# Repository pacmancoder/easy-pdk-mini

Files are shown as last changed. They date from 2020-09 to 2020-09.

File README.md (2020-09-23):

# easy-pdk-mini

Easy PDK mini is the programmer hardware variant originated from
[easy-pdk-programmer-hardware](https://github.com/free-pdk/easy-pdk-programmer-hardware) project.

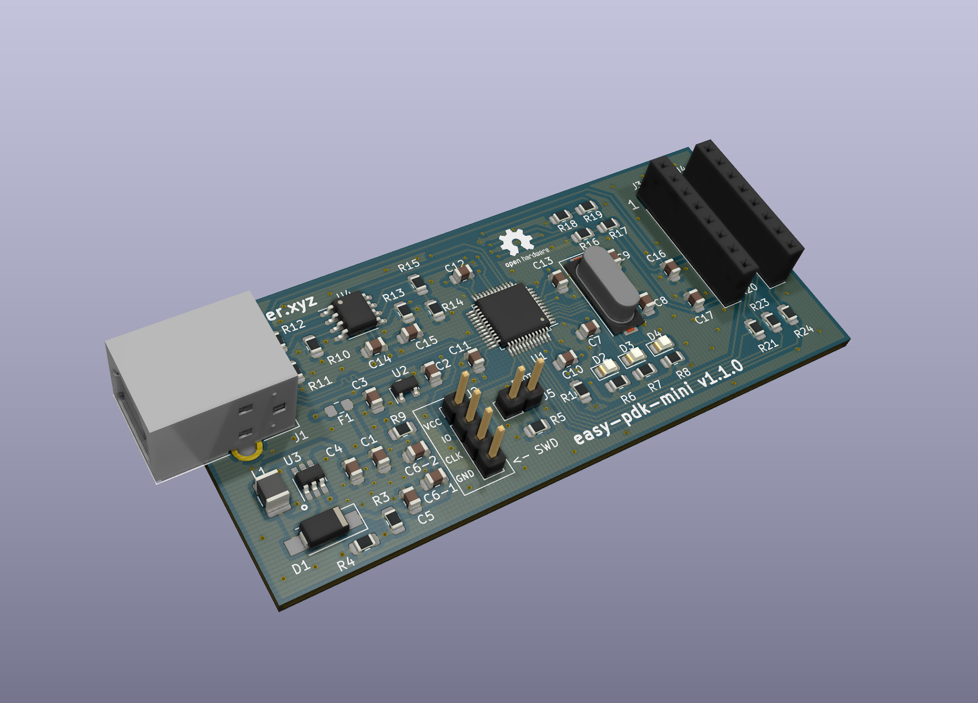
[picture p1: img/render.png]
render


Schematics was simplified and the "lite" version of the programmer by *tim_* was used as a base for
this project, so in difference with the original hardware, this version works without MOSFET boost
converter enable switch and negative voltage charge pump for the opamp.

*Interactive BOM:* [link](http://pacmancoder.xyz/easy-pdk-mini/)

### Hand soldering
All passives have at least 0805 size, and the USB-B port was used instead of micro-USB, so it
should be easy to solder this programmer by the hand. The only quirky parts which may be
hard to solder is STM32 MCU and MT3608 boost converter. 

### Changes
Although existing "lite" version of easy-pdk-programmer (which was used as a reference for this
project) is relatively simple by itself, some additional simplifications was made:
- Removed 20Ohm USB series resistors. According to STM32F072 datasheet: *"No external termination
series resistors are required on USB_DP (D+) and USB_DM (D-); the matching impedance is already
included in the embedded driver"*
- Replaced boot button with simple jumper
- Replaced 47uF boost converter output capacitor with two 22uF caps to simplify process of finding
components (In my city I was not able to find 47uF 16v, while it was easy to find 22uF 25V)
- Added pull-down resistor for PB8 to make programmer detect as "lite" hardware
- Added 500mA 6v PTC fuse

### Schematics
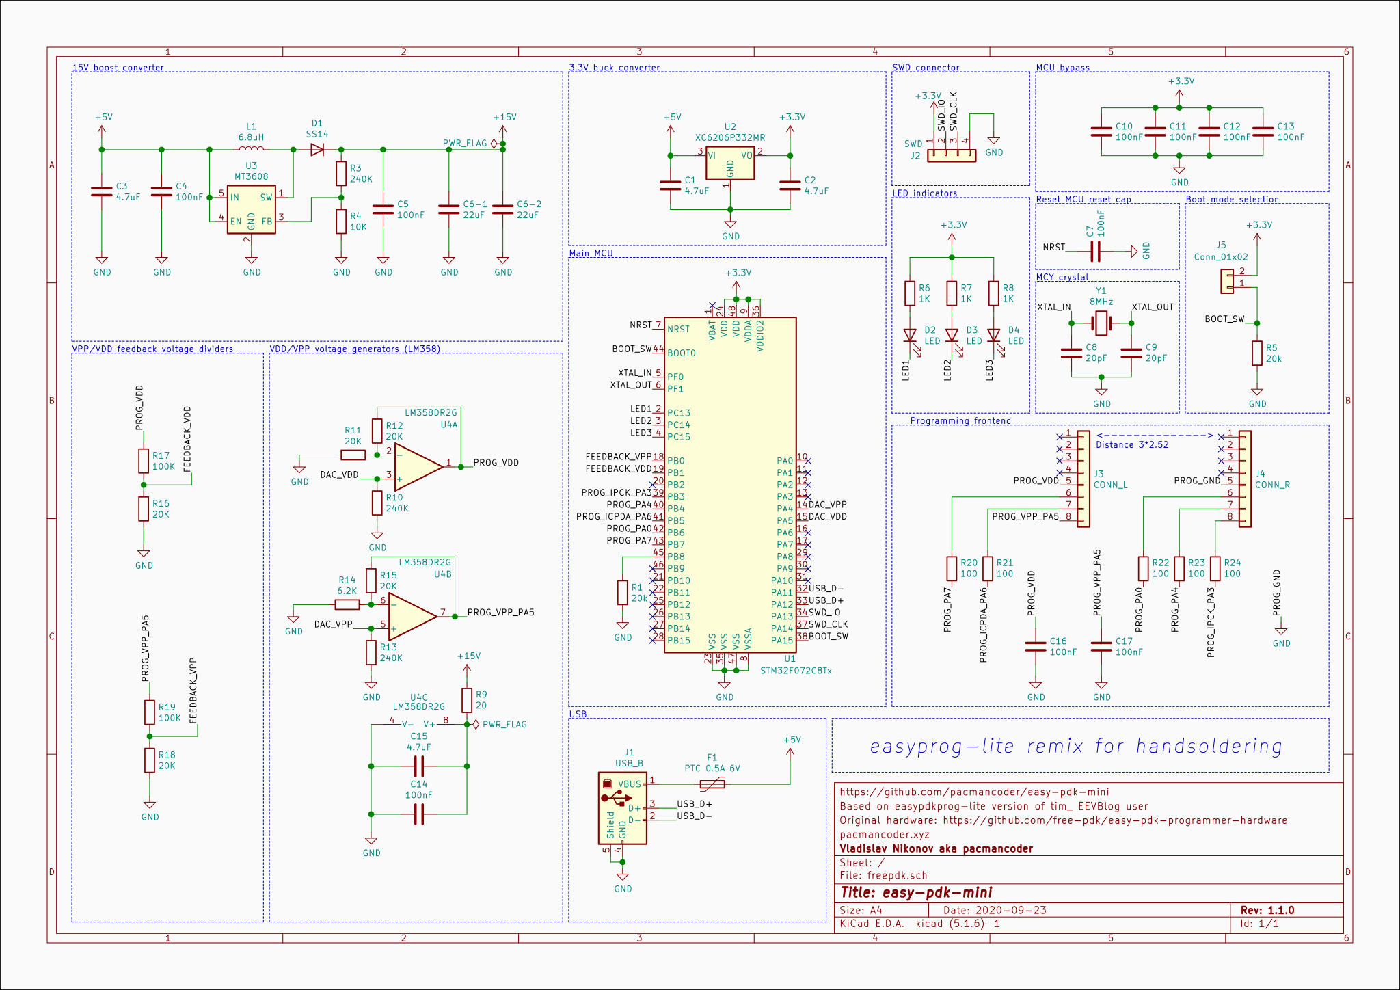
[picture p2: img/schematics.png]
schematics


### PCB
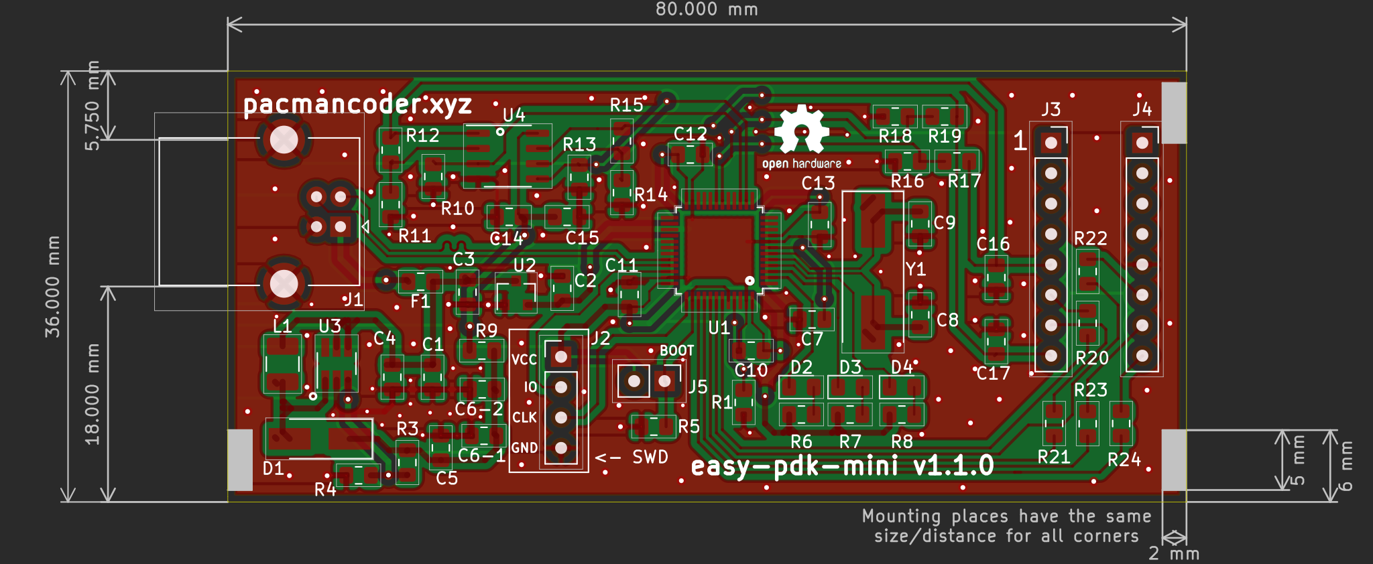
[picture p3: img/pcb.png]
pcb


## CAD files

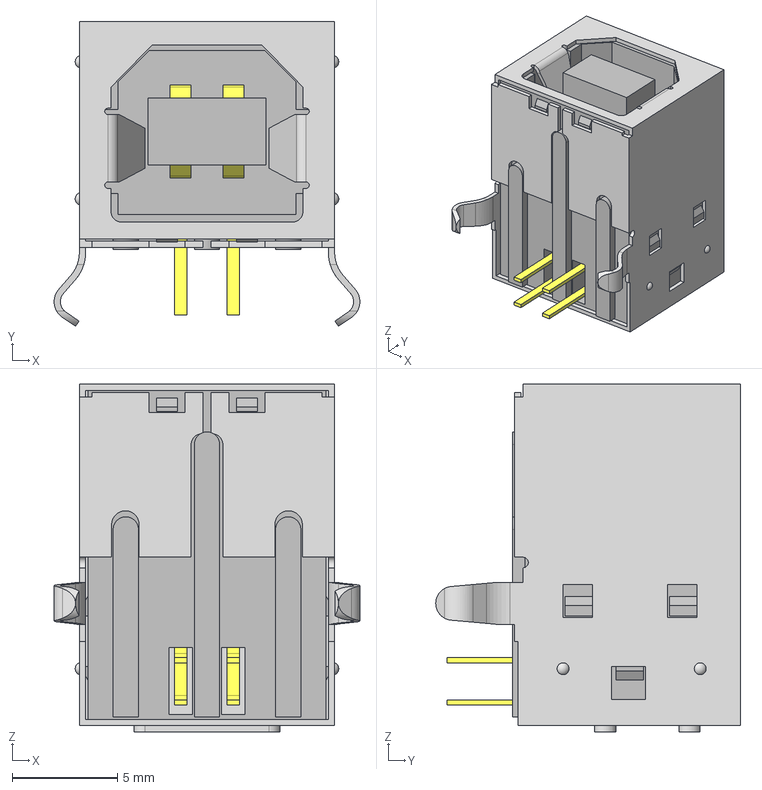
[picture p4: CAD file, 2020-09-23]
kicad/components/USB-B-S-S-B-TH-TR.stp
14.5 x 14.4 x 16.5 mm
_USB-B-S-TH_S
_USB-B-S-B-TH_B
_USB-B-S-TH_P

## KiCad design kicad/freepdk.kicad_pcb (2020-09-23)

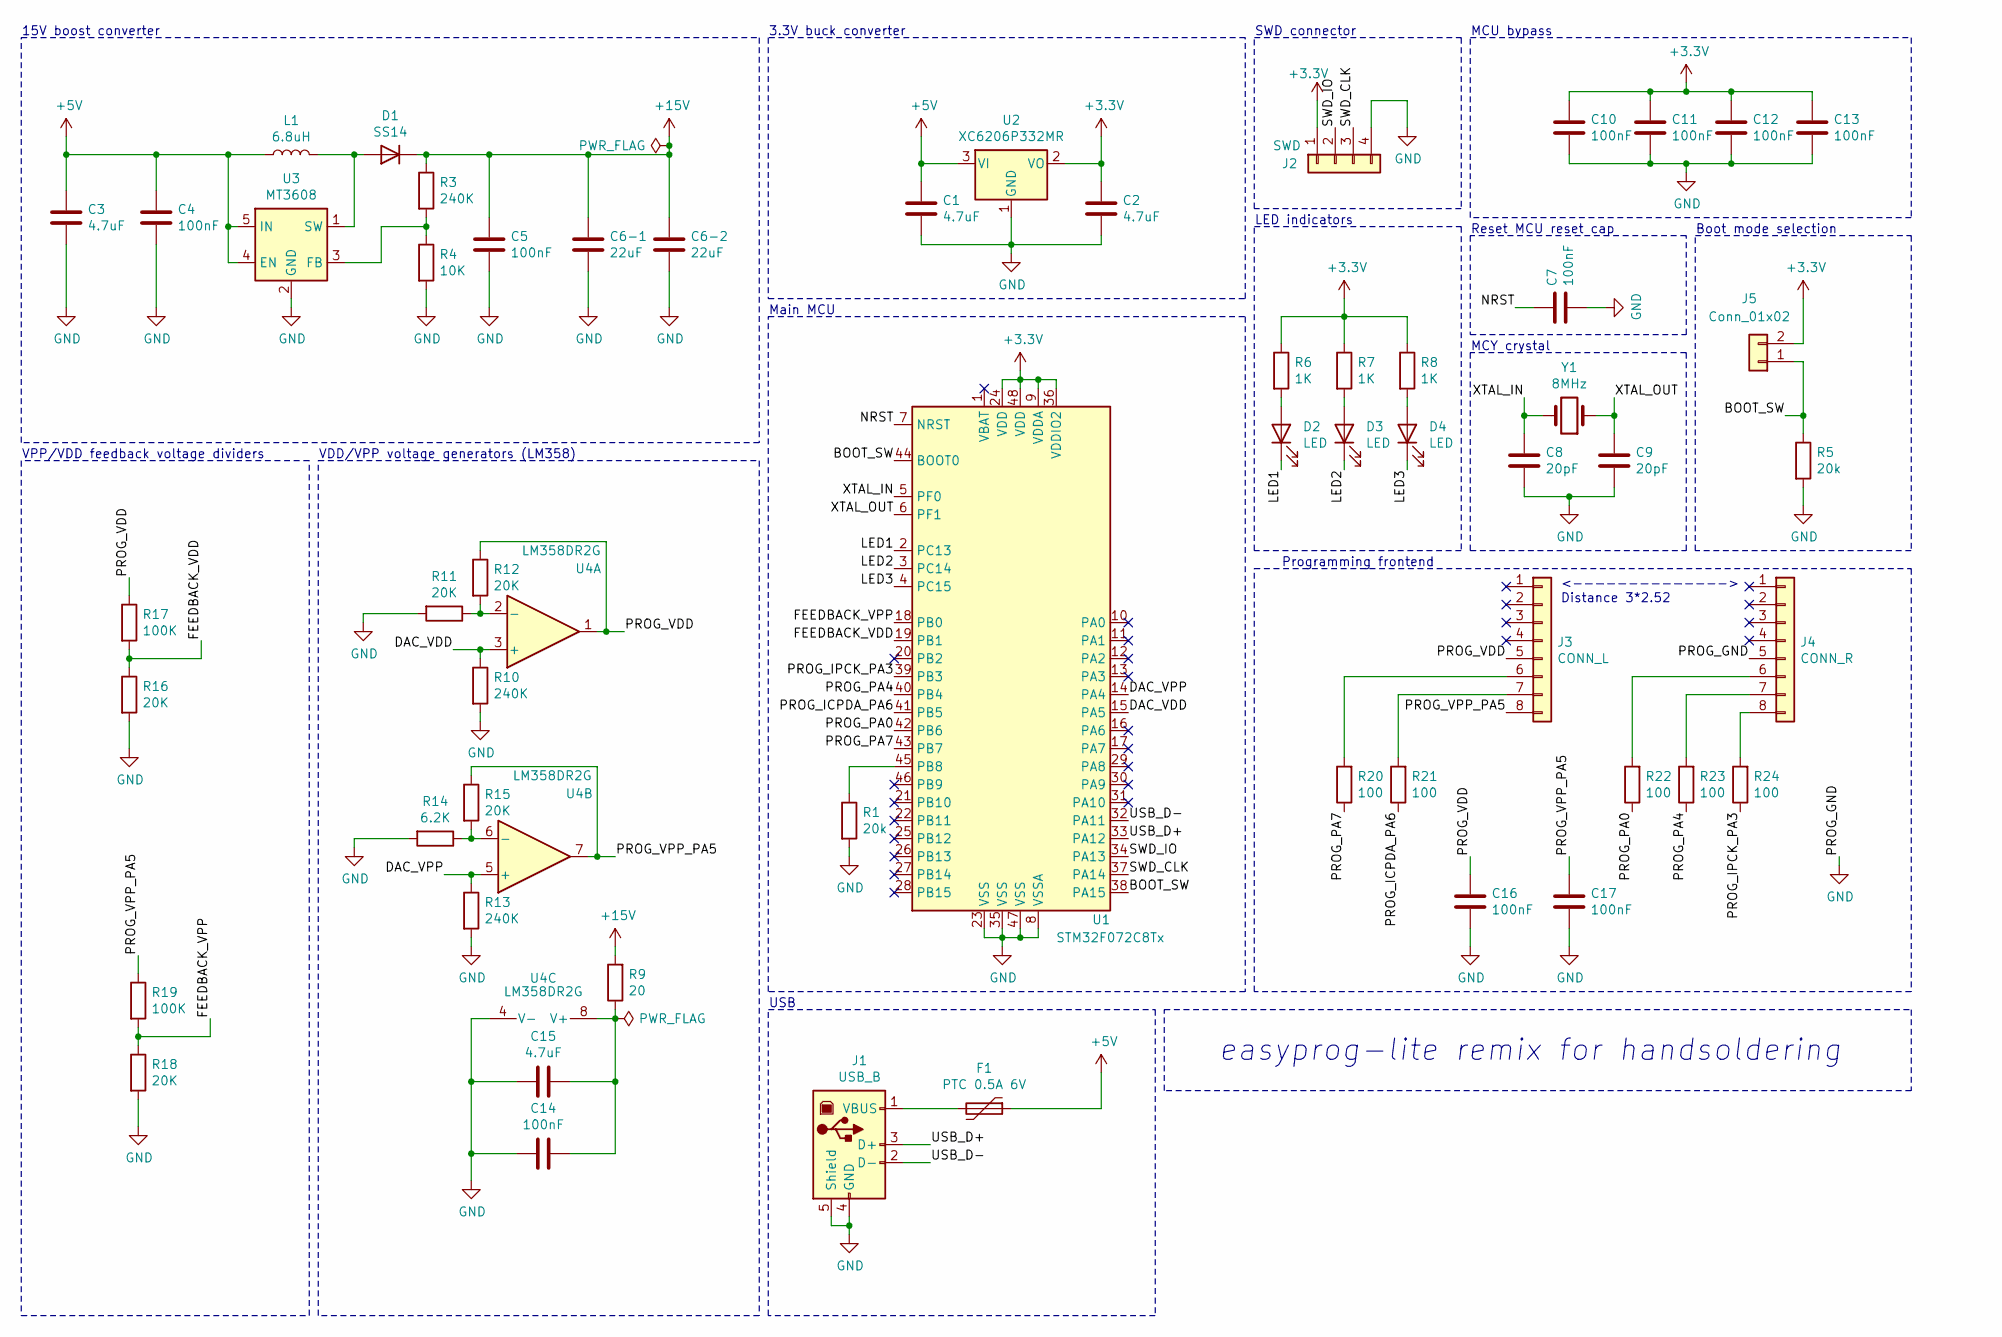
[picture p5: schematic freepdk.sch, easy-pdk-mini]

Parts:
C1, C2, C3, C15: 4.7uF; C_0805_2012Metric_Pad1.15x1.40mm_HandSolder
C4, C5, C7, C10, C11, C12, C13, C14, C16, C17: 100nF; C_0805_2012Metric_Pad1.15x1.40mm_HandSolder
C6-1, C6-2: 22uF; C_0805_2012Metric_Pad1.15x1.40mm_HandSolder
C8, C9: 20pF; C_0805_2012Metric_Pad1.15x1.40mm_HandSolder
D1: SS14; D_SMA_Handsoldering
D2, D3, D4: LED; LED_0805_2012Metric_Pad1.15x1.40mm_HandSolder
F1: PTC 0.5A 6V; Fuse_0805_2012Metric_Pad1.15x1.40mm_HandSolder
J1: USB_B; USB_B_OST_USB-B1HSxx_Horizontal
J2: SWD; PinHeader_1x04_P2.54mm_Vertical
J3: CONN_L; PinSocket_1x08_P2.54mm_Vertical
J4: CONN_R; PinSocket_1x08_P2.54mm_Vertical
J5: Conn_01x02; PinHeader_1x02_P2.54mm_Vertical
L1: 6.8uH; L_1210_3225Metric_Pad1.42x2.65mm_HandSolder
R1, R5: 20k; R_0805_2012Metric_Pad1.15x1.40mm_HandSolder
R3, R10, R13: 240K; R_0805_2012Metric_Pad1.15x1.40mm_HandSolder
R4: 10K; R_0805_2012Metric_Pad1.15x1.40mm_HandSolder
R6, R7, R8: 1K; R_0805_2012Metric_Pad1.15x1.40mm_HandSolder
R9: 20; R_0805_2012Metric_Pad1.15x1.40mm_HandSolder
R11, R12, R15, R16, R18: 20K; R_0805_2012Metric_Pad1.15x1.40mm_HandSolder
R14: 6.2K; R_0805_2012Metric_Pad1.15x1.40mm_HandSolder
R17, R19: 100K; R_0805_2012Metric_Pad1.15x1.40mm_HandSolder
R20, R21, R22, R23, R24: 100; R_0805_2012Metric_Pad1.15x1.40mm_HandSolder
U1: STM32F072C8Tx; LQFP-48_7x7mm_P0.5mm
U2: XC6206P332MR; SOT-23
U3: MT3608; SOT-23-6_Handsoldering
U4: LM358DR2G; SOIC-8_3.9x4.9mm_P1.27mm
Y1: 8MHz; Crystal_SMD_HC49-SD

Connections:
+3V3: C2.1, C10.1, C11.1, C12.1, C13.1, J2.1, J5.2, R6.1, R7.1, R8.1, U1.9 (VDDA), U1.24 (VDD), U1.36 (VDDIO2), U1.48 (VDD), U2.2 (VO)
+5V: C1.1, C3.1, C4.1, F1.1, L1.1, U2.3 (VI), U3.4 (EN), U3.5 (IN)
+15V: C5.1, C6-1.1, C6-2.1, D1.1 (K), R3.1, R9.2
/BOOT_SW: J5.1, R5.1, U1.38 (PA15), U1.44 (BOOT0)
/DAC_VDD: R10.1, U1.15 (PA5), U4.3 (+)
/DAC_VPP: R13.1, U1.14 (PA4), U4.5 (+)
/FEEDBACK_VDD: R16.1, R17.2, U1.19 (PB1)
/FEEDBACK_VPP: R18.1, R19.2, U1.18 (PB0)
/LED1: D2.1 (K), U1.2 (PC13)
/LED2: D3.1 (K), U1.3 (PC14)
/LED3: D4.1 (K), U1.4 (PC15)
/NRST: C7.1, U1.7 (NRST)
/PROG_ICPDA_PA6: R21.1, U1.41 (PB5)
/PROG_IPCK_PA3: R24.1, U1.39 (PB3)
/PROG_PA0: R22.1, U1.42 (PB6)
/PROG_PA4: R23.1, U1.40 (PB4)
/PROG_PA7: R20.1, U1.43 (PB7)
/PROG_VDD: C16.1, J3.5, R12.1, R17.1, U4.1
/PROG_VPP_PA5: C17.1, J3.8, R15.1, R19.1, U4.7
/SWD_CLK: J2.3, U1.37 (PA14)
/SWD_IO: J2.2, U1.34 (PA13)
/USB_D+: J1.3 (D+), U1.33 (PA12)
/USB_D-: J1.2 (D-), U1.32 (PA11)
/XTAL_IN: C8.2, U1.5 (PF0), Y1.2
/XTAL_OUT: C9.2, U1.6 (PF1), Y1.1
GND: C1.2, C2.2, C3.2, C4.2, C5.2, C6-1.2, C6-2.2, C7.2, C8.1, C9.1, C10.2, C11.2, C12.2, C13.2, C14.2, C15.2, C16.2, C17.2, J1.4 (GND), J1.5 (Shield), J2.4, J4.5, R1.2, R4.2, R5.2, R10.2, R11.2, R13.2, R14.2, R16.2, R18.2, U1.8 (VSSA), U1.23 (VSS), U1.35 (VSS), U1.47 (VSS), U2.1 (GND), U3.2 (GND), U4.4 (V-)
unnamed: C14.1, C15.1, R9.1, U4.8 (V+)
unnamed: D1.2 (A), L1.2, U3.1 (SW)
unnamed: D2.2 (A), R6.2
unnamed: D3.2 (A), R7.2
unnamed: D4.2 (A), R8.2
unnamed: F1.2, J1.1 (VBUS)
unnamed: J3.6, R20.2
unnamed: J3.7, R21.2
unnamed: J4.6, R22.2
unnamed: J4.7, R23.2
unnamed: J4.8, R24.2
unnamed: R1.1, U1.45 (PB8)
unnamed: R3.2, R4.1, U3.3 (FB)
unnamed: R11.1, R12.2, U4.2 (-)
unnamed: R14.1, R15.2, U4.6 (-)

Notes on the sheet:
SWD connector
Programming frontend
MCY crystal
MCU bypass
LED indicators
Reset MCU reset cap
Boot mode selection
3.3V buck converter
Main MCU
USB
VDD/VPP voltage generators (LM358)
VPP/VDD feedback voltage dividers
15V boost converter
easyprog-lite remix for handsoldering
<--------------> Distance 3*2.52

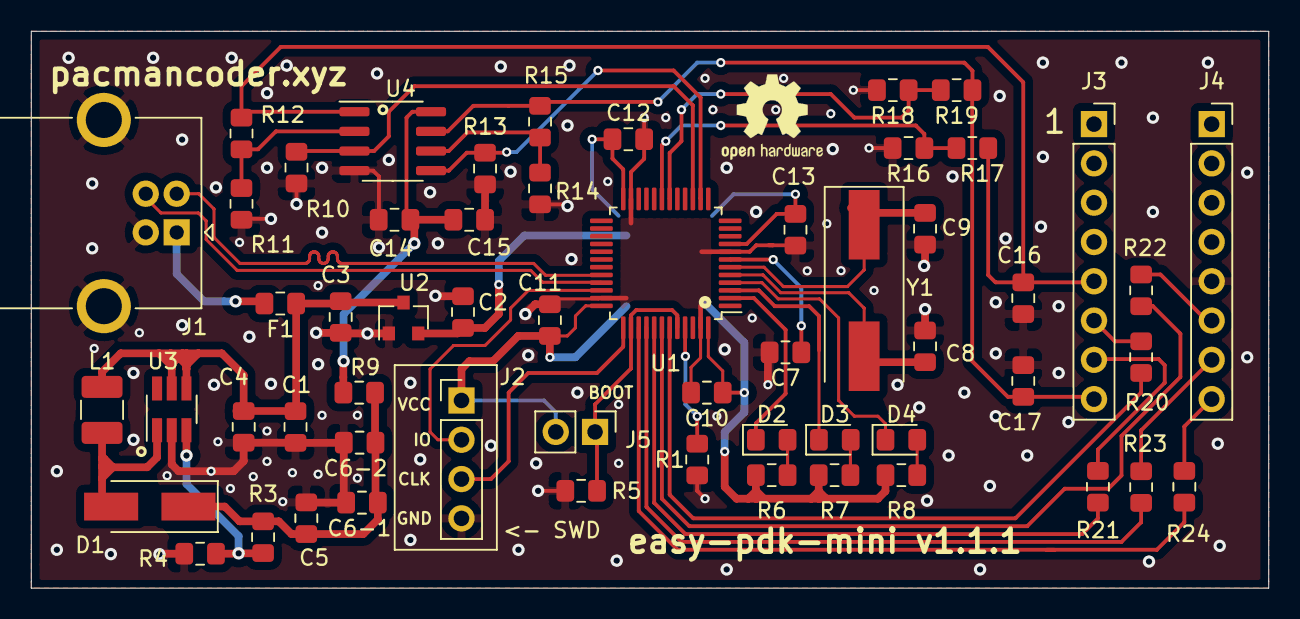
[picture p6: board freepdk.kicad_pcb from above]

Board: 2 copper layers, 80.0 x 36.0 mm, 57 parts (0 on the bottom side), 41 nets.

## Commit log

2020-09-06 First revision
    [freepdk.kicad_pcb, freepdk.sch]
2020-09-07 Second revision - Added fuse, improved routing, changed pcb dimentsions
    [freepdk.kicad_pcb, freepdk.sch]
2020-09-07 Fixed silkscreen and markings
    [freepdk.kicad_pcb, freepdk.sch]
2020-09-07 Added Interactive BOM
2020-09-08 Revision 3 - Applied suggestions from review, prepared gerbers
    [freepdk-B_Cu.gbr, freepdk-B_Mask.gbr, freepdk-B_Paste.gbr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]
2020-09-08 Revision 3 patch: Replaced wrong opamp; Removed logo from BOM
    [freepdk.kicad_pcb, freepdk.sch]
2020-09-08 Fixed interactive BOM link
2020-09-19 Fixed issue with wrong opamp wiring
    [freepdk.kicad_pcb, freepdk.sch]
2020-09-23 Updated PCB to use USB-B port instead of Mini-usb
    [USB-B-S-S-B-TH-TR.stp, freepdk.kicad_pcb, freepdk.sch]
2020-09-23 Updated gerbers for v1.1.0
    [freepdk-B_Cu.gbr, freepdk-B_Mask.gbr, freepdk-B_Paste.gbr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]
2020-09-23 Updated interactive BOM and updated gerbers after minor bugfixes
    [freepdk-B_Cu.gbr, freepdk-B_Mask.gbr, freepdk-B_Paste.gbr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]

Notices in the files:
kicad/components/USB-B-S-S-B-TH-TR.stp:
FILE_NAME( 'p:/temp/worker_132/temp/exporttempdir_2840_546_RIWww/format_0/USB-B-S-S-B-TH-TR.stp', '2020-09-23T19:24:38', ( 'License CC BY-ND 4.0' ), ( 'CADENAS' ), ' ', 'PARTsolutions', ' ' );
